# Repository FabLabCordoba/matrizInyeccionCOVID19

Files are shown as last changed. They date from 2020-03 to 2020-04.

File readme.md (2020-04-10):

# Corona Injection
### Matriz de inyección de plástico Open-Source para protectores faciales.

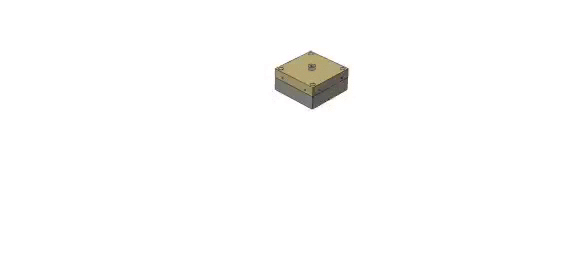
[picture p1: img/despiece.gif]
Despiece


La comunidad maker de Argentina se unió para dar una respuesta a la crisis sanitaria desatada por COVID19. Mientras se imprimía en 3D sin descanso, se desarrolló la presente matriz de inyección de plástico con la intención de lograr una producción masiva al menor costo posible.

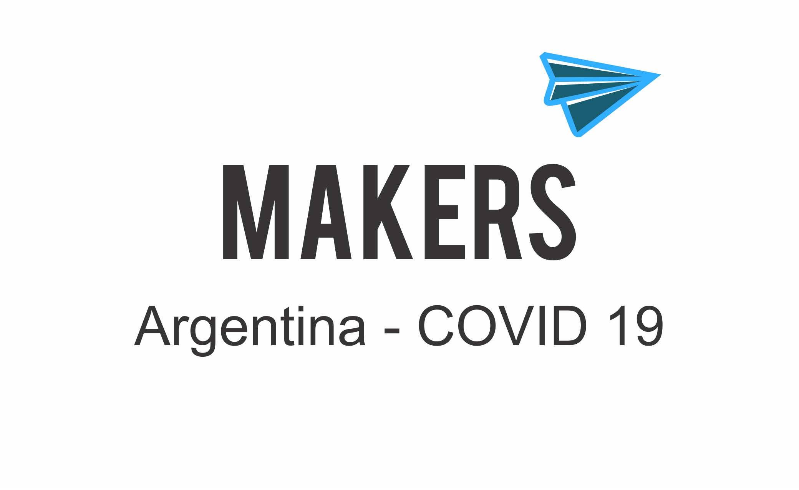
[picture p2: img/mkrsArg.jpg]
Makers Argentina

Más de 800 Makers autoconvocados de todo el país decidieron poner sus impresoras 3D al servicio del sistema de salud y la comunidad en general para prevenir más contagios a causa del COVID-19.

## Especificaciones técnicas
Ver [informe](https://github.com/FabLabCordoba/matrizInyeccionCOVID19/blob/master/Informe.pdf).

## Licencia

[Atribución-NoComercial-CompartirIgual 4.0 Internacional (CC BY-NC-SA 4.0)](https://creativecommons.org/licenses/by-nc-sa/4.0/deed.es)
Para un uso comercial, por favor contactarnos.

## (participantes)
+ Coordinación general
    + [Fundación FabLab Córdoba](http://fablabcordoba.org)
    + [Mi 3DP](http://www.facebook.com/mi3dp)
    + [DIP - Diseño y Prototipado](mailto:dip3dcba@gmail.com)
+ Gestión operativa:
    + [Omnicraft](https://omnicraft3d.com/)

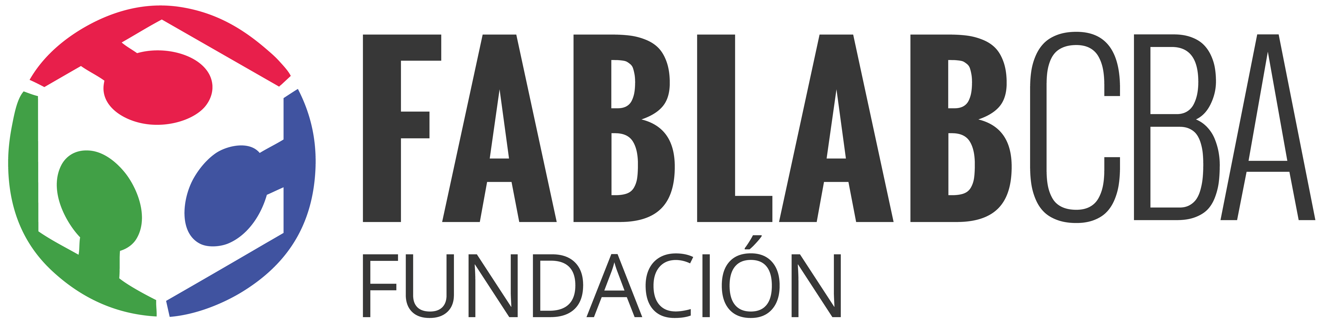
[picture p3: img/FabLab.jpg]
FabLab Córdoba

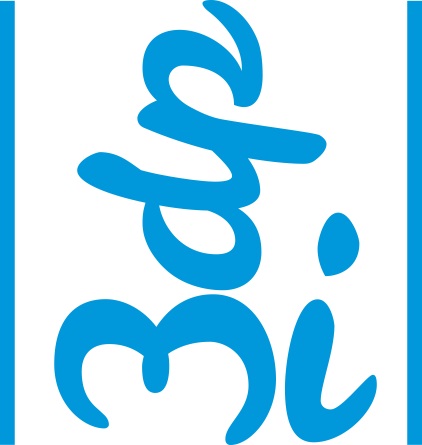
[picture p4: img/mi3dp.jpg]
Mi 3DP

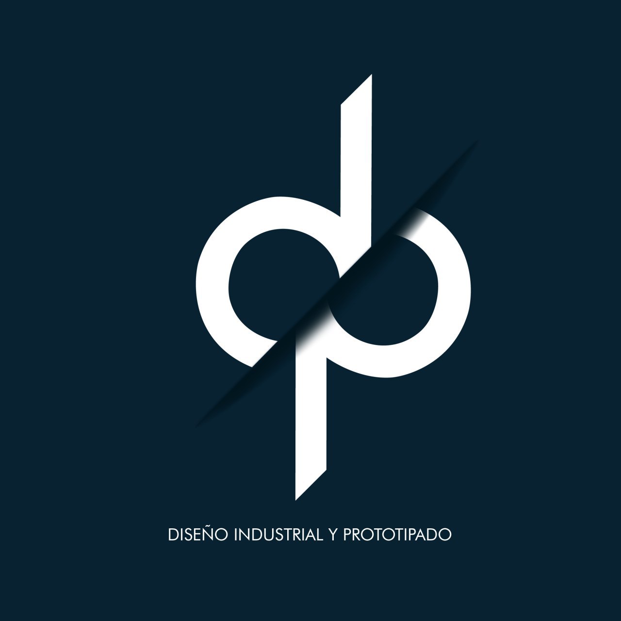
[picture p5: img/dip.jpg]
DIP

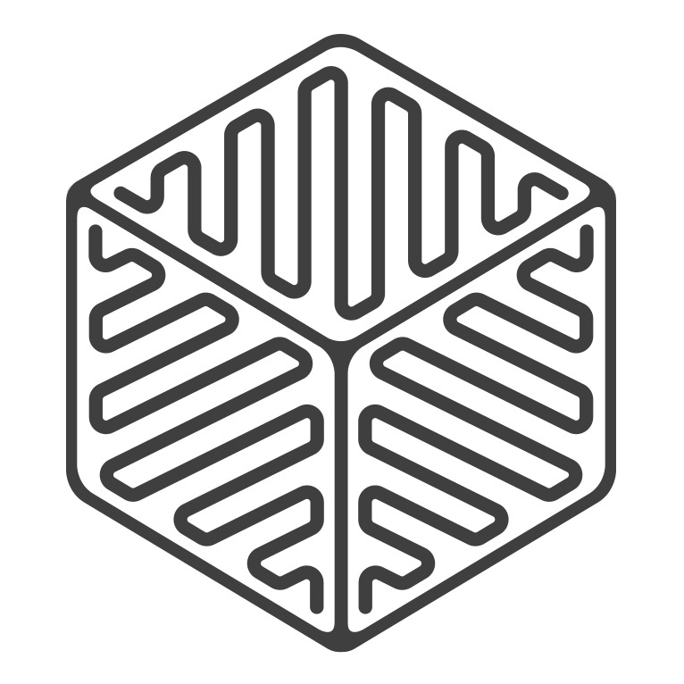
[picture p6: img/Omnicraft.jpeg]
Omnicraft

Makers Argentina

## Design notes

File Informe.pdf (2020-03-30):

Mascara Facial modificación (4-4) 28-03-2020 1

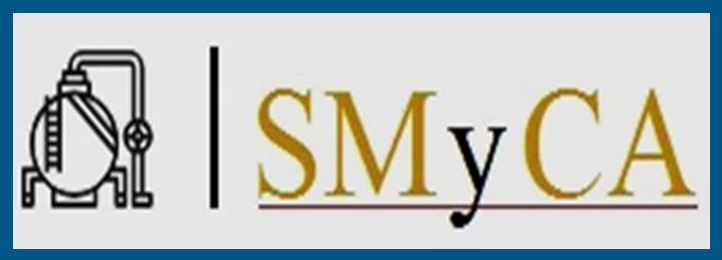
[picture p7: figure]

La Calera, Córdoba, Argentina 29-03.2020

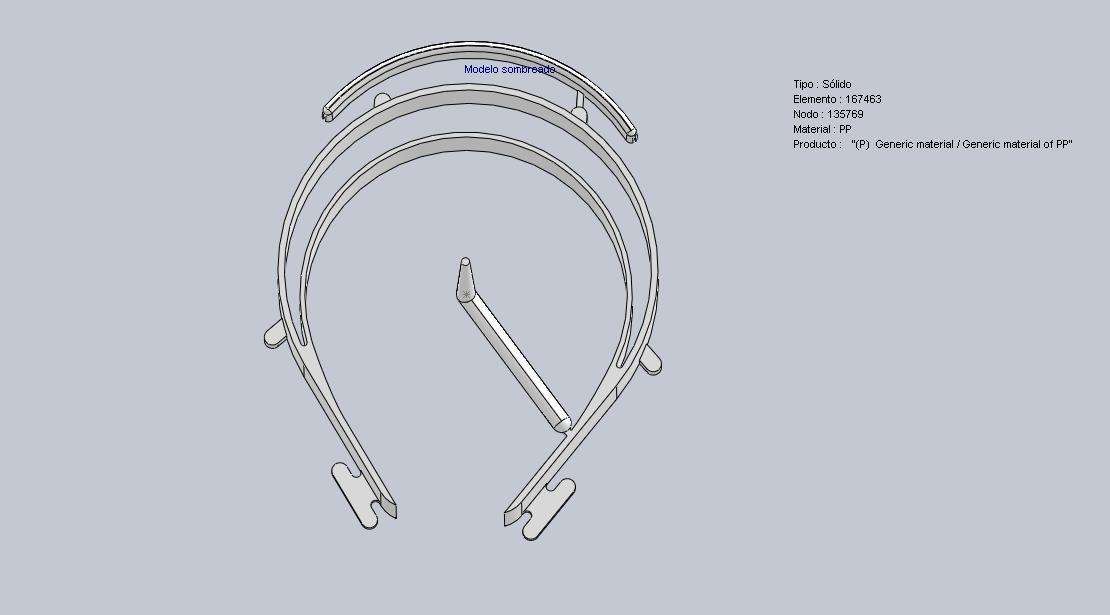
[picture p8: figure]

# Mascara Facial

Protectora.

Fecha: 29-03.2020
Diseñador: Jorge Luis Altamirano Análisis: Sólido/ Modelo Totalmente Sólido

## Tabla de contenidos

Introducción ..... ¡Error! Marcador no definido.

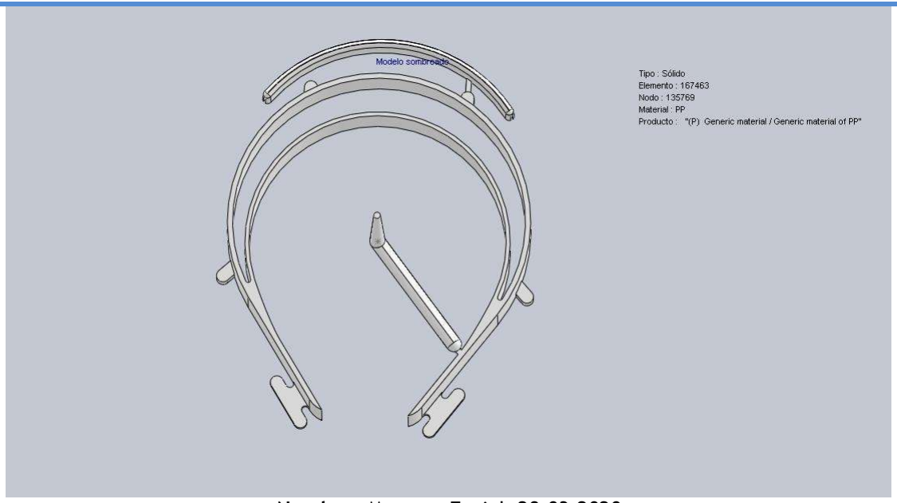
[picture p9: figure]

Servicios Metalurgicos y de Calderas Altamirano | Jorge Luis Altamirano 28-03-2020 2

La Calera, Córdoba, Argentina 29-03.2020

## Informaciones modelo

Comentarios:

Nombre: Mascara Facial 28-03-2020 Configuración actual: Predeterminado
Nombre | Predeterminado
Tipo | Sólido
Elemento | -----
Nodo | -----
Cara de simetría | No
Volumen | 28843.88 (mm3)
Peso | 27.45 (gr)
Dimensiones | 123.82 (mm) x 155.41 (mm) x 70.40 (mm)

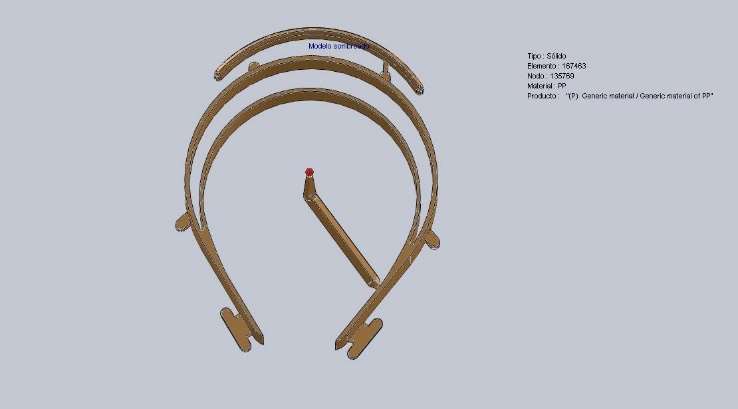
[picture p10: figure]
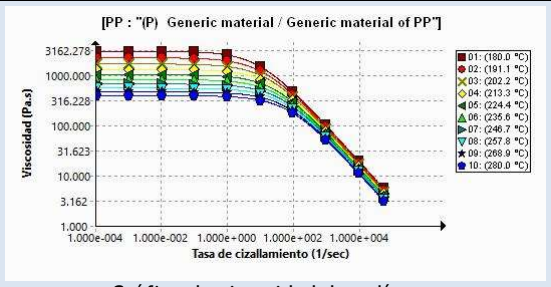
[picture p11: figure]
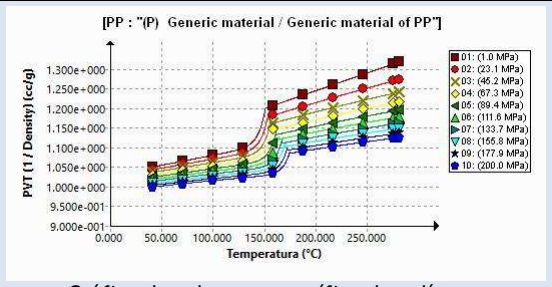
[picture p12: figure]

Servicios Metalurgicos y de Calderas Altamirano | Jorge Luis Altamirano 28-03-2020 3

## Propiedades de material

Comentarios:

## Polímero

Referencia de modelo | Propiedades

Nombre de
material
| PP

Nombre del
producto
| "(P) Generic material / Generic material of PP"

Temperatura del
material
| 230.00 °C

Temperatura del
molde
| 50.00 °C

Temperatura de
eyección
| 95.00 °C

Temperatura de
transición
cristalina
| 135.00 °C
| Calor específico 3.100000e+007 erg/(g-C) Conductividad 1.500000e+004 erg/(sec- cm-K)

Módulo de
elasticidad
| 1.350000e+010 dyne/cm2

Coeficiente de
Poisson
| 4.000000e-001

Datos de curva:

Gráfico de viscosidad de polímero | Gráfico de volumen específico de polímero

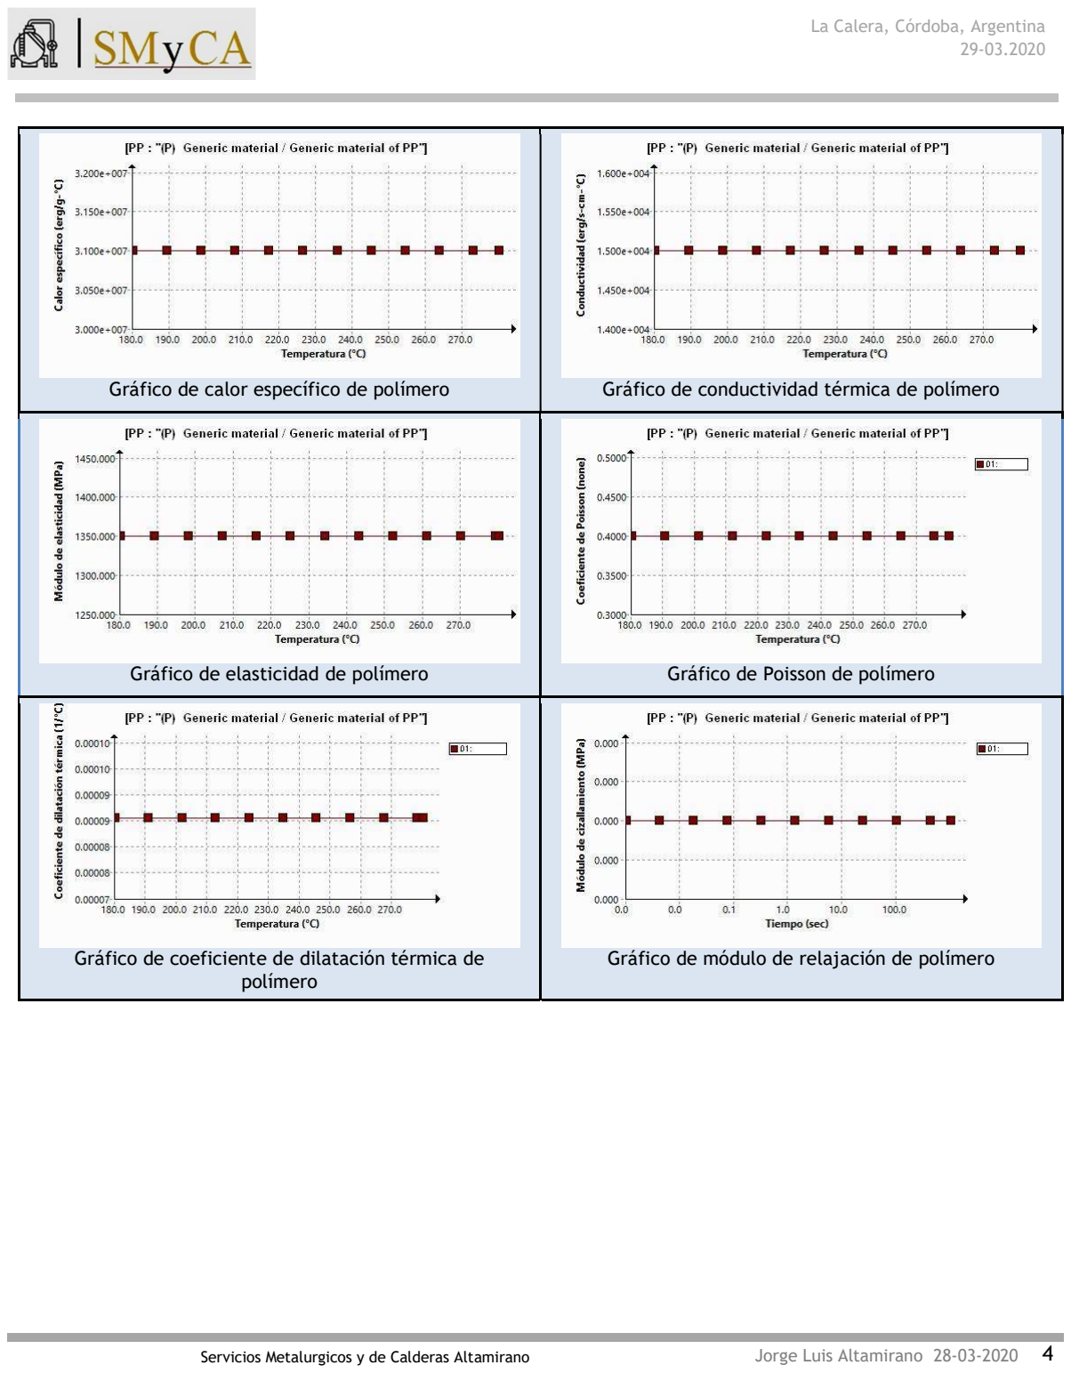
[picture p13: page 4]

Servicios Metalurgicos y de Calderas Altamirano | Jorge Luis Altamirano 28-03-2020 4
Gráfico de calor específico de polímero | Gráfico de conductividad térmica de polímero
Gráfico de elasticidad de polímero | Gráfico de Poisson de polímero

Gráfico de coeficiente de dilatación térmica de polímero

Gráfico de módulo de relajación de polímero

Servicios Metalurgicos y de Calderas Altamirano | Jorge Luis Altamirano 28-03-2020 5

## Parámetros del proceso

Comentarios:

## Ajustes de llenado

Tiempo de llenado | 2.72 sec (aproximado)
Temperatura Fusión Material Principal | 230 °C
Temperatura pared molde | 50 °C
Presión máxima de inyección | 100 MPa (aproximado)
Flujo de inyección máximo (máquina) | A definir
Punto de cambio Flow/Pack en Volumen Llenado | 100 %
Tiempo de mantenimiento de la presión | 4.56 sec (aproximado)
Tiempo Total de la Etapa de Empaquetado | 27.23 sec (aproximado)
Tiempo de llenado automático (1: Existe, 0: No) | 1
Tiempo de empaquetado automático (1: Existe, 0: No) | 1
Análisis de ventilación (1: Existe, 0: No) | 0
Presión Inicial del Aire de la Cavidad | 0.1 MPa
Temperatura Inicial del Aire de la Cavidad | 25 °C

Servicios Metalurgicos y de Calderas Altamirano | Jorge Luis Altamirano 28-03-2020 6

## Resultados Flow

Comentarios:

## Resumen de Flow

Fuerza de Cierre X-dir. | 8.7897 Tonne (9.6900 Ton U.S)
Fuerza de Cierre Y-dir. | 7.7120 Tonne (8.5000 Ton U.S)
Fuerza de Cierre Z-dir. | 3.1800 Tonne (3.5000 Ton U.S)
Presión de inyección Requerida | 22.8693 MPa (3320.0000 psi)
Temperatura ponderada máxima | 230.7958 °C (447.0000 °F)
Tensiones de Cizalla Máx | 0.1453 MPa (21.1000 psi)
Tiempo de CPU | ---
Tiempo de ciclo Estimado: | 51.64 sec (A definir)

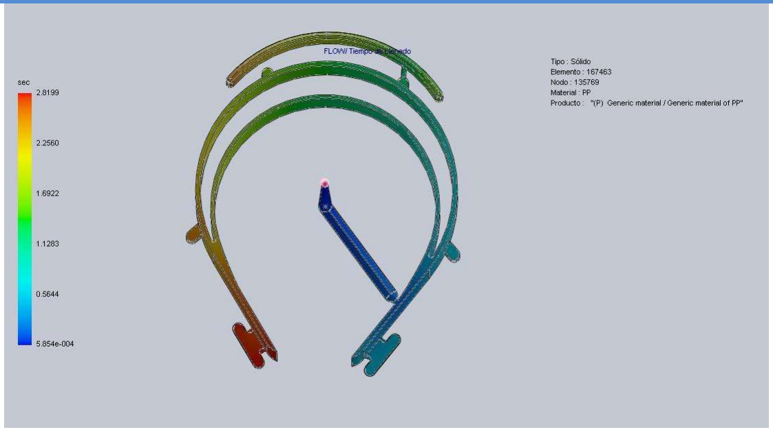
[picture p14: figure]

Servicios Metalurgicos y de Calderas Altamirano | Jorge Luis Altamirano 28-03-2020 7
Nombre | Tipo | Mín | Máx
Tiempo de Llenado | Resultados Flow | 0.000585 | 2.819881

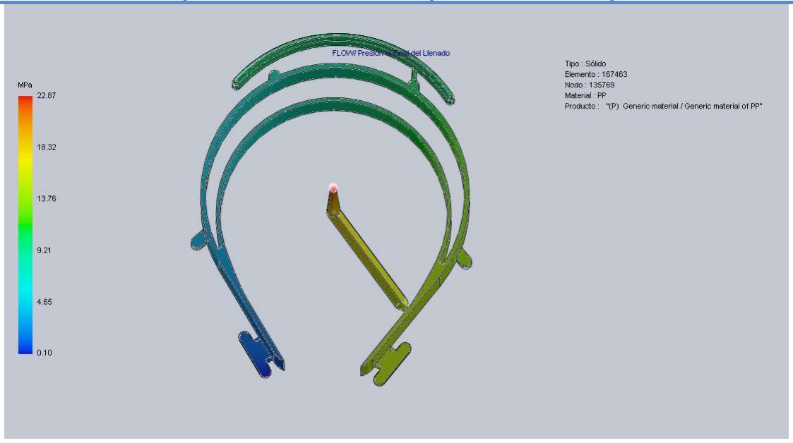
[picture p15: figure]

Servicios Metalurgicos y de Calderas Altamirano | Jorge Luis Altamirano 28-03-2020 8
Nombre | Tipo | Mín | Máx
Presión al Final del Llenado | Resultados Flow | 0.100000 | 22.869289

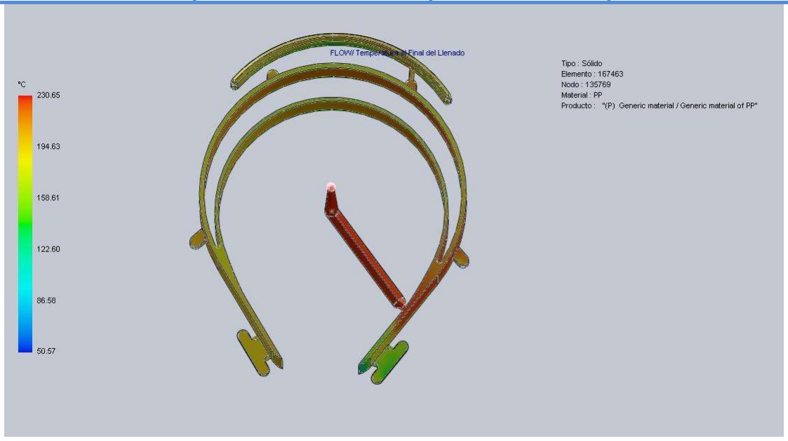
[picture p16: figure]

Servicios Metalurgicos y de Calderas Altamirano | Jorge Luis Altamirano 28-03-2020 9
Nombre | Tipo | Mín | Máx
Temperatura al Final del Llenado | Resultados Flow | 50.568260 | 230.645798

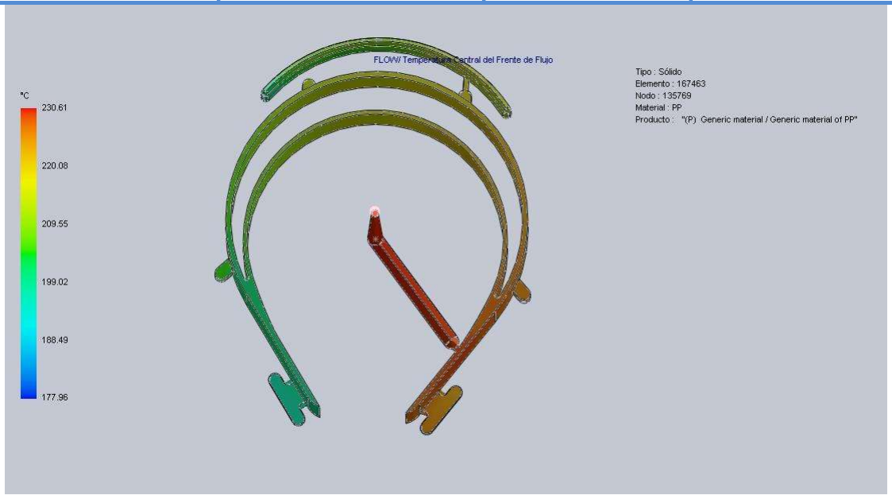
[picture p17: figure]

Servicios Metalurgicos y de Calderas Altamirano | Jorge Luis Altamirano 28-03-2020

1
0
Nombre | Tipo | Mín | Máx
Temperatura Central del Frente de Flujo | Resultados Flow | 177.958603 | 230.606201

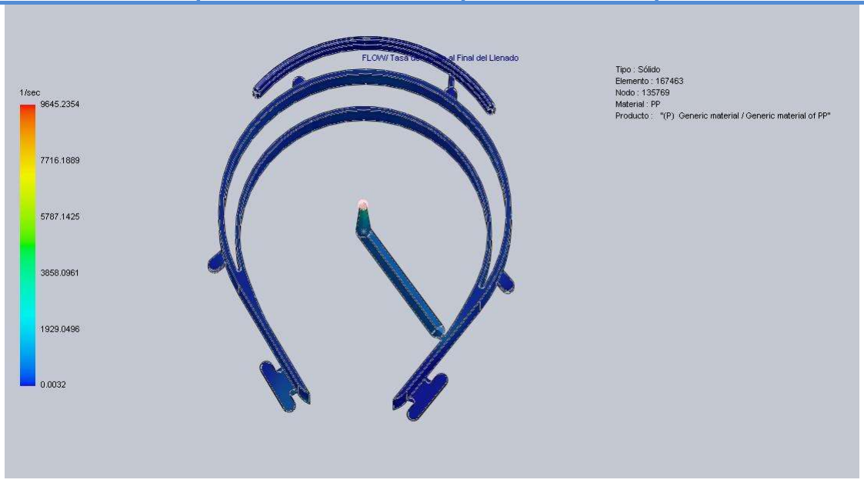
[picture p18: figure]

1
1
Nombre | Tipo | Mín | Máx
Tasa de Cizalla al Final del Llenado | Resultados Flow | 0.003218 | 9645.235352

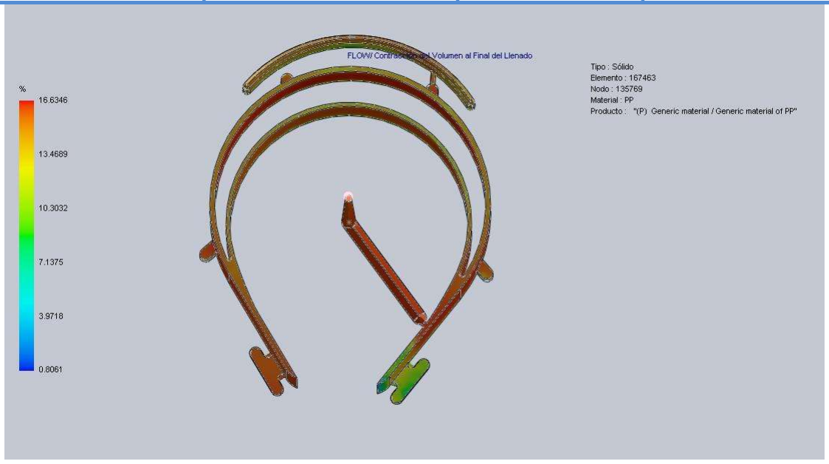
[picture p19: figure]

1
2
Nombre | Tipo | Mín | Máx
Contracción del Volumen al Final del Llenado | Resultados Flow | 0.806073 | 16.634569

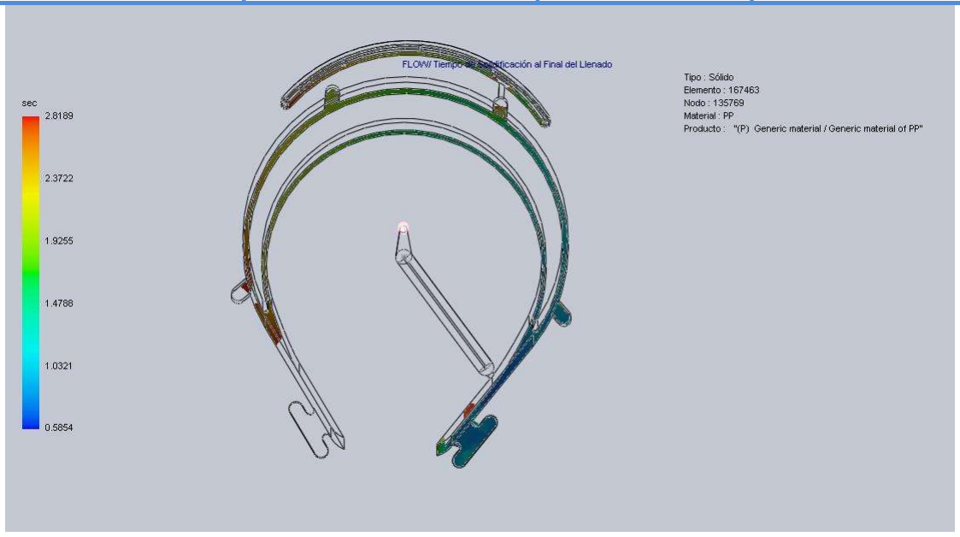
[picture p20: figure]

1
3
Nombre | Tipo | Mín | Máx
Tiempo de Solidificación al Final del Llenado | Resultados Flow | 0.585384 | 2.818920

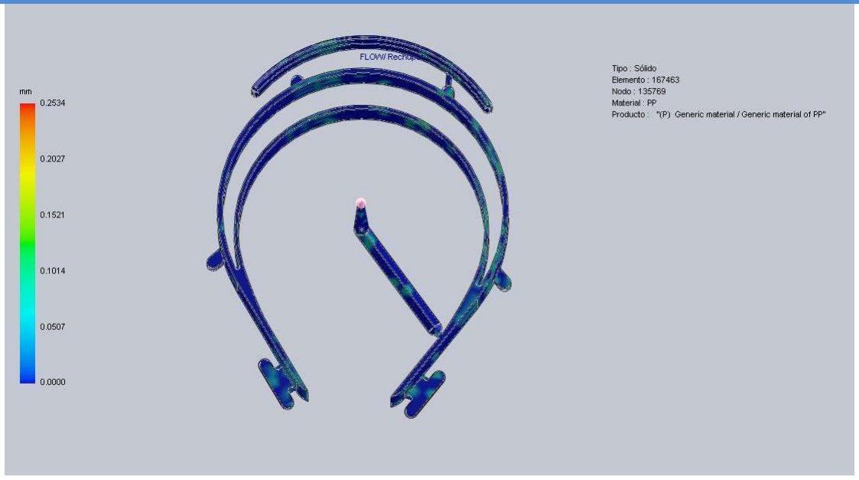
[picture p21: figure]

1
4
Nombre | Tipo | Mín | Máx
Rechupes | Resultados Flow | 0.000000 | 0.253437

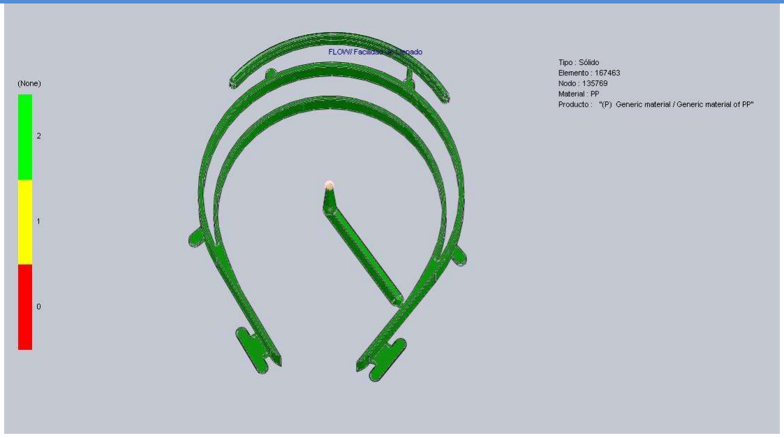
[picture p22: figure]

1
5
Nombre | Tipo | Mín | Máx
Facilidad de Llenado | Resultados Flow | 0.000000 | 2.000000

1
6

## Conclusión:

Según la simulación y el estudio de la pieza y el molde que se ha realizado hasta el momento, es un molde que dentro de la sencillez de la concepción del mismo, para bajar costos de materiales y tiempos de fabricación, va a responder de manera correcta al proceso de inyección, este es un informe de etapa de desarrollo, en los próximos días, se va a realizar un detallado informe (conjunto con los modelados y planos del molde y modelo), de los criterios tomados para llegar a definir el molde de esta manera, ya que se ha desarrollado rápidamente debido a que estaba definido y al haber cambios en la pieza a pedido del ministerio de salud se tuvo que remodelar el mismo desde el día viernes, y que se busca un rápido proceso de mecanizado para que comience a producir lo antes posible.

Por el momento sin otro particular.

Les Saluda atte.

Jorge Luis Altamirano.
Diseño y Desarrollo.
smyca.servicios@gmail.com
3572-570427
SMyCA.

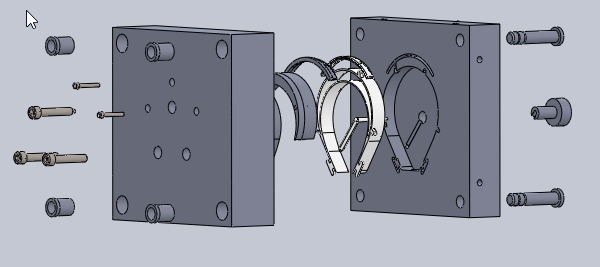
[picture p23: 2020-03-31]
img/despiece1.png

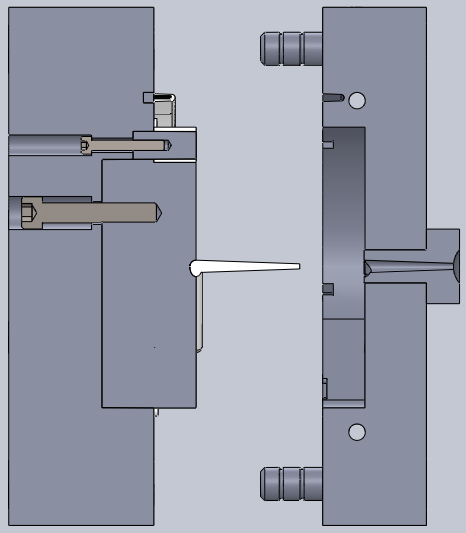
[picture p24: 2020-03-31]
img/lateral1.png

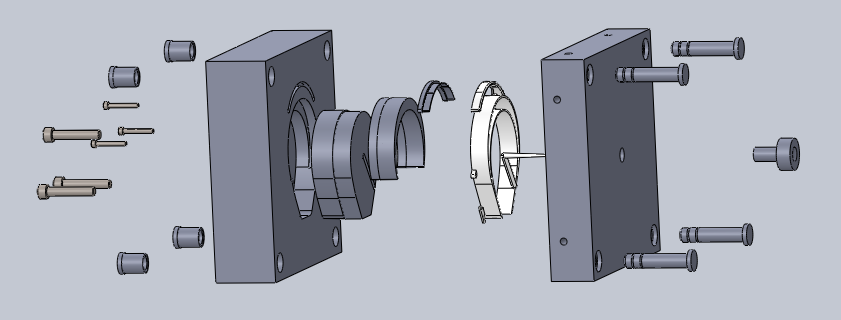
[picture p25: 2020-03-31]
img/despiece0.png

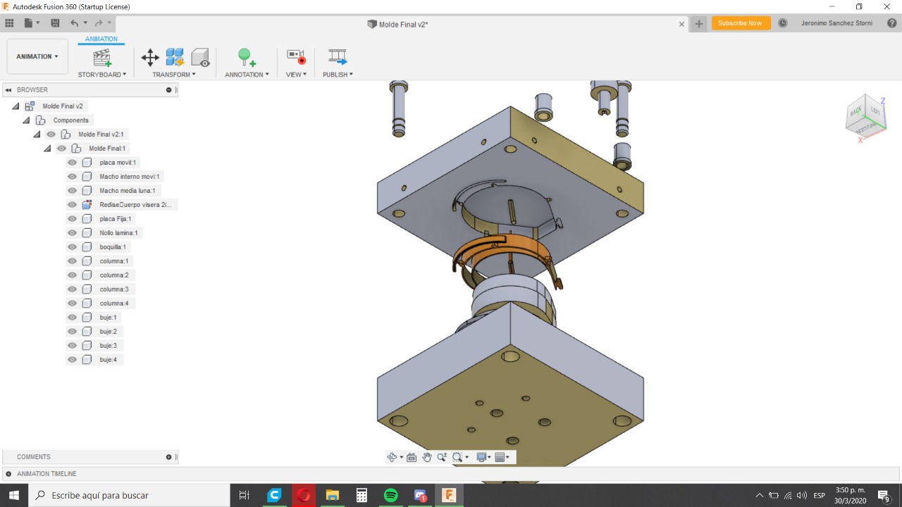
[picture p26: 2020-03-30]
img/Molde1.jpeg

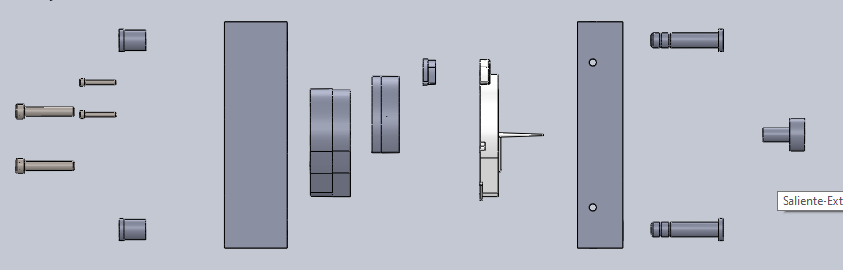
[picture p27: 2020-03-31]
img/despieceLateral.png

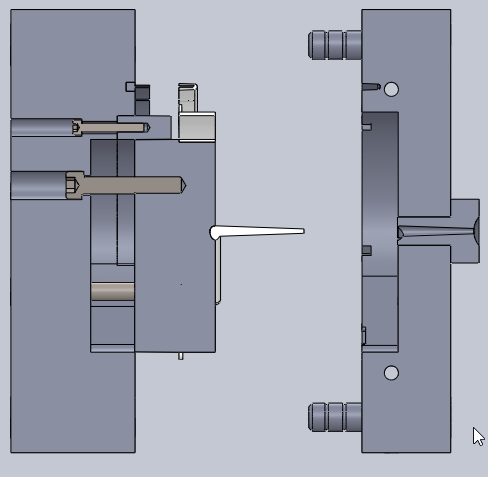
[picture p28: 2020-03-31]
img/lateral0.png

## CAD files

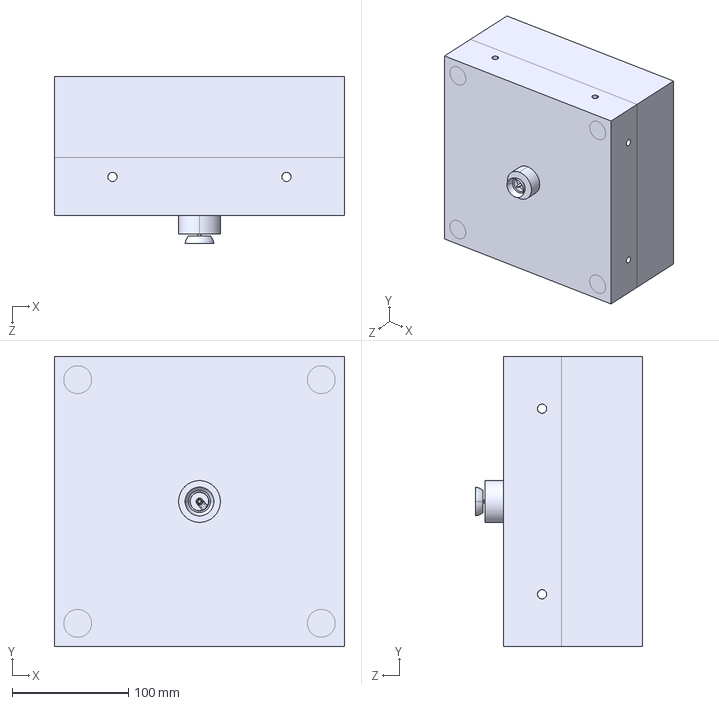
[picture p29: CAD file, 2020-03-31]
Molde para liberar.IGS
250.0 x 250.0 x 144.0 mm

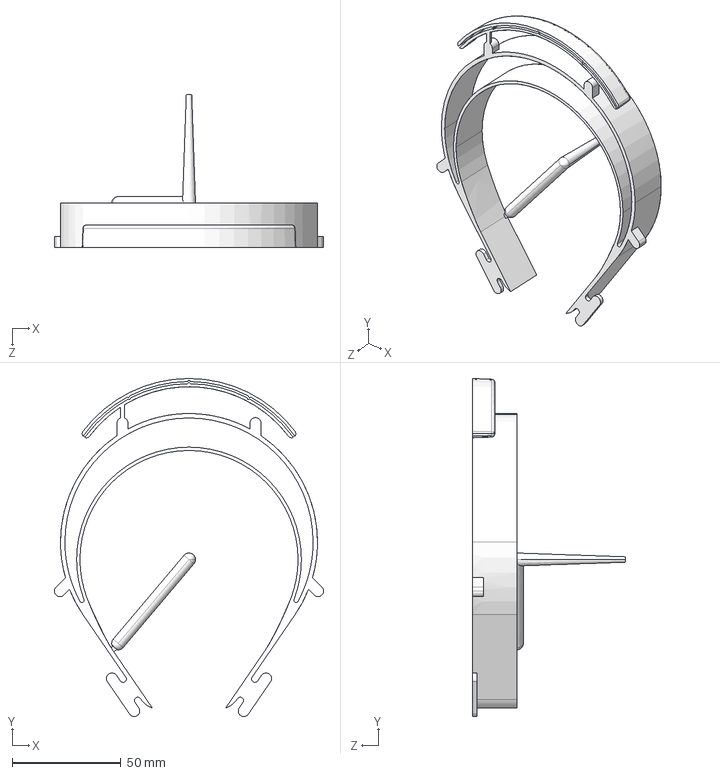
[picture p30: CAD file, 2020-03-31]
Modelado de pieza escalado.IGS
123.9 x 155.6 x 70.4 mm

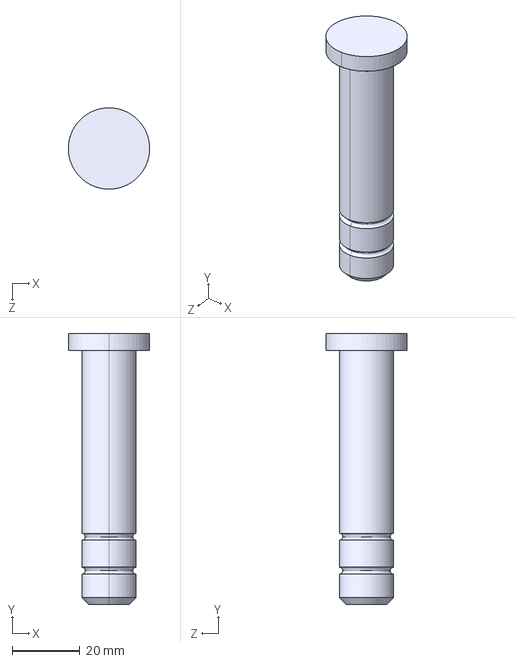
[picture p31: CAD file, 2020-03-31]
columna.IGS
24.0 x 80.0 x 24.0 mm

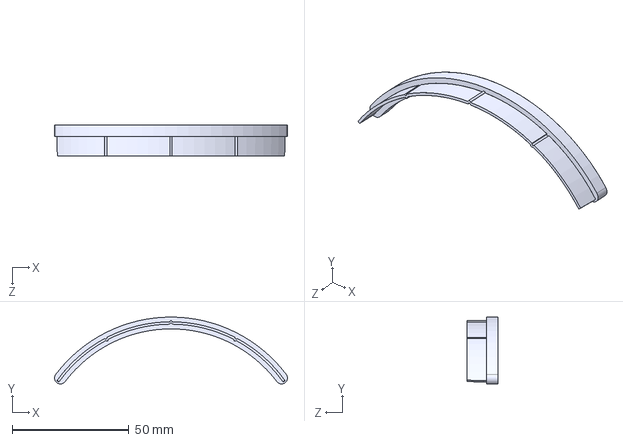
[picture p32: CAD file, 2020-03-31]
Nollo lamina.IGS
99.6 x 28.6 x 13.3 mm

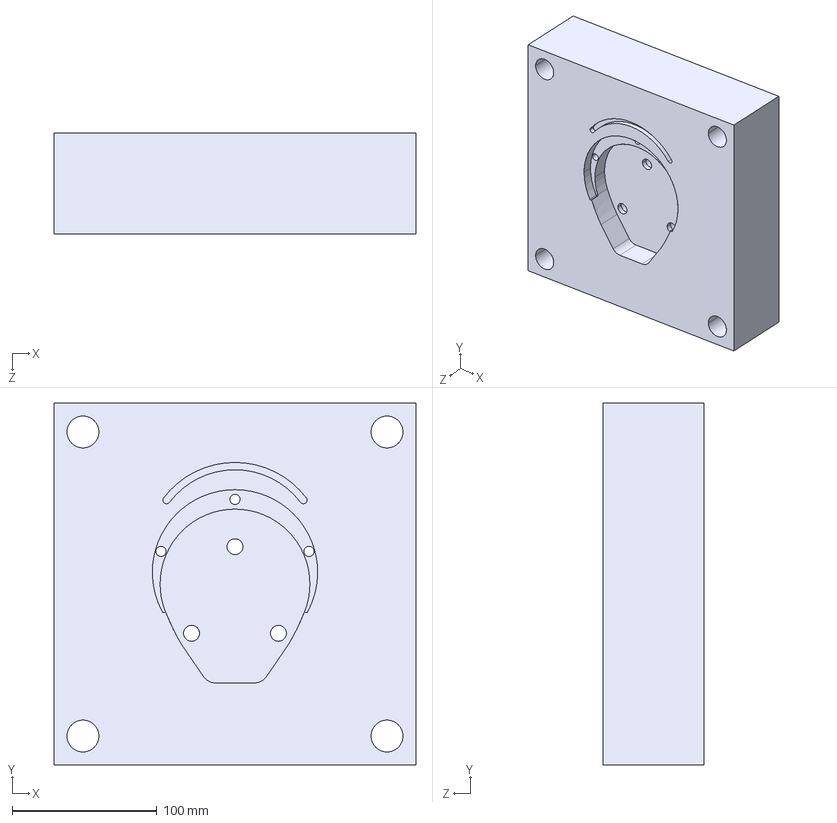
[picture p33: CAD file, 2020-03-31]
placa movil.IGS
250.0 x 250.0 x 70.0 mm

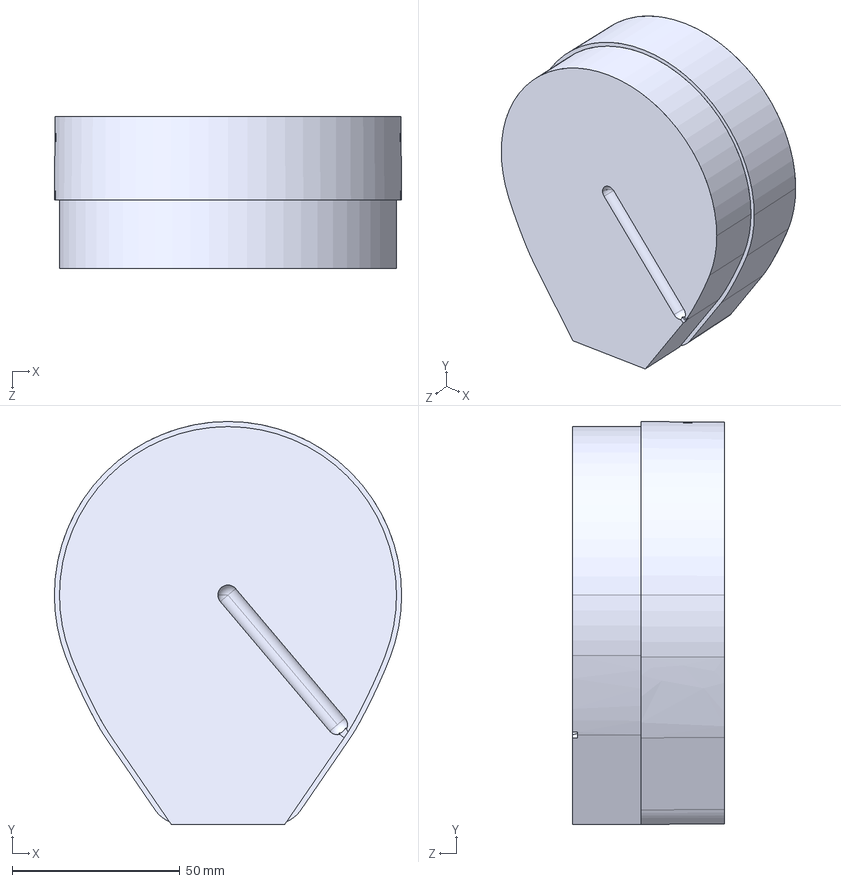
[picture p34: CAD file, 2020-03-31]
Macho interno movi.IGS
103.4 x 120.0 x 45.4 mm

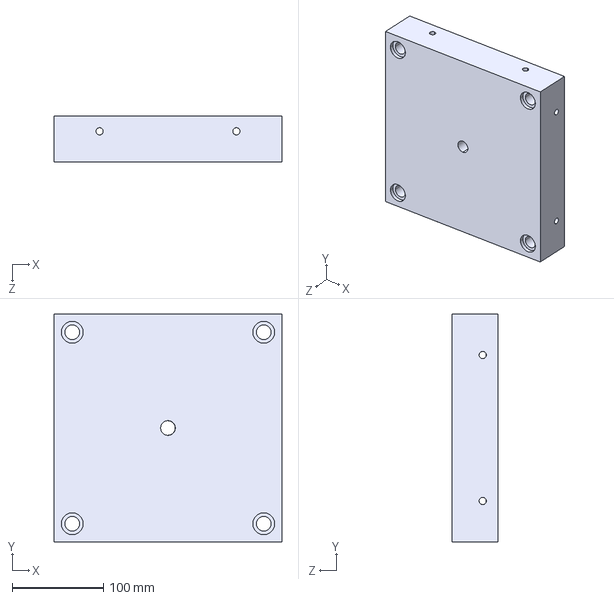
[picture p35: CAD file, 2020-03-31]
placa Fija.IGS
250.0 x 250.0 x 50.0 mm

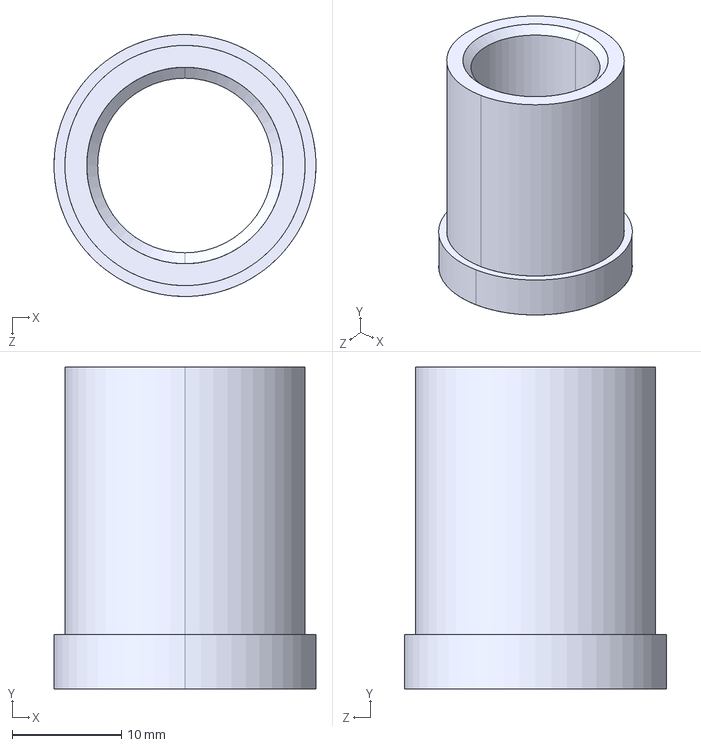
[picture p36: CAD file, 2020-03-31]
buje.IGS
24.0 x 29.5 x 24.0 mm

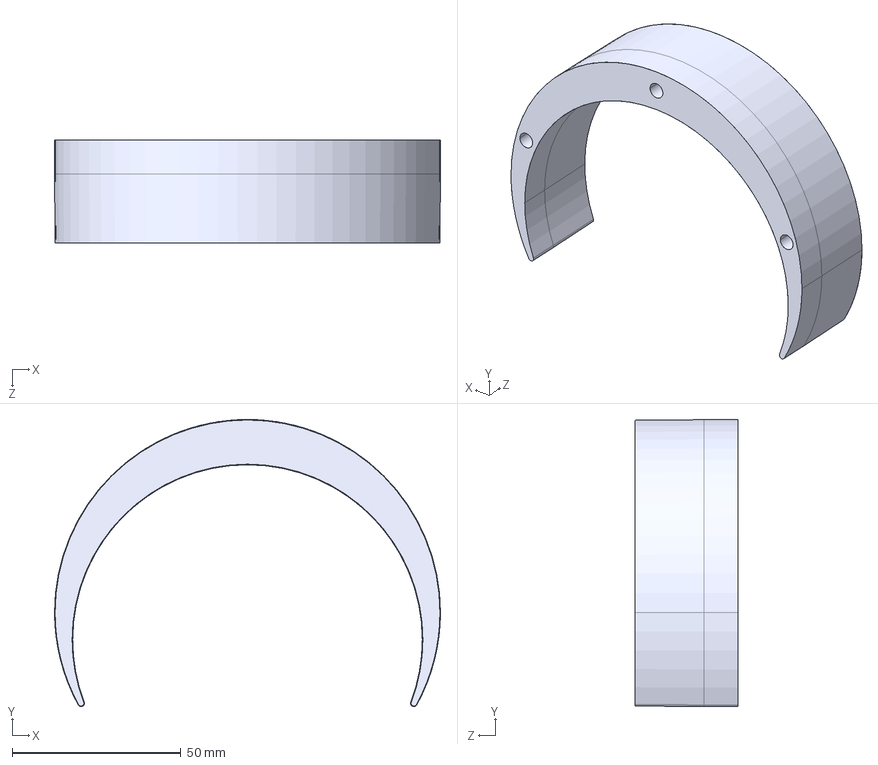
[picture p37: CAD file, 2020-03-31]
Macho media luna.IGS
114.2 x 85.0 x 30.4 mm

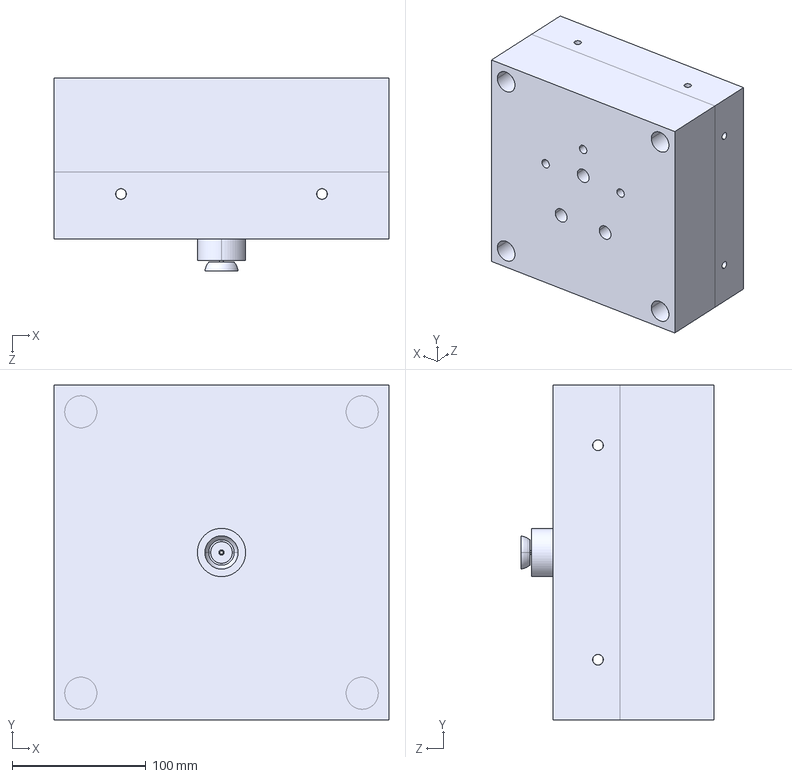
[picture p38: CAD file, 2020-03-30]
Molde.igs
250.0 x 250.0 x 144.0 mm

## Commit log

2020-03-30 IGS e informe.
    [Molde.igs]
2020-03-31 Nueva version.
    [Macho interno movi.IGS, Macho media luna.IGS, Modelado de pieza escalado.IGS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]
